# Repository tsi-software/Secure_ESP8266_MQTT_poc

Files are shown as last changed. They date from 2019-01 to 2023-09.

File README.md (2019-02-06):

# Secure ESP8266 MQTT proof of concept
*Copyright (c) 2019 Warren Taylor.*

There are many in depth and well documented ESP8266 MQTT tutorials out there. This in not one of them. This is a brief proof of concept where “security first” is the focus, rather than an afterthought. The goal of this project is to have a documented and working **secure** MQTT Broker and Client, which can be used as a reference for later projects.
If you’re a first timer this project probably isn’t for you.

## Disclaimer
The following documentation in no way guarantees a secure system.
*See [LICENSE](LICENSE).*

## Features
- MQTT Publish/Subscribe Messaging secured using TLS 1.2
- OTA (Over-the-air) Client firmware updates.
- As of this writing esp8266 Secure Encrypted OTA is still in beta.

# Top Level Components
- Secure MQTT Server setup
- Secure ESP8266 MQTT Client
- AVR SPI Slave

# High Level Design 

## Secure MQTT Broker
The MQTT Broker named Mosquitto is installed on the OpenWRT Wifi router. Running the MQTT Broker on the Wifi router is an experiment, which has so far worked just fine. However, the MQTT Broker could be run on any other computer on the same local area network (LAN). You could even run it on a Raspberry PI if performance isn’t a strict requirement.
<br>[MQTT Broker secure setup - detail](top-level-components/mqtt_server_setup#mqtt-broker-secure-setup)

## Secure ESP8266 MQTT Client
Again, there are many tutorials on how to program the ESP8266 as an MQTT Client. But it's hard to find a single source clearly describing how to program the ESP8266 as a **secure** MQTT Client. As a long time software engineer I know how important security is these days.
<br>[Secure ESP8266 MQTT Client - detail](top-level-components/secure_esp8266_mqtt_client#secure-esp8266-mqtt-client)

## AVR SPI Slave
The original plan was to connect peripherals directly to the ESP8266 data pins but I ran out of pins very quickly. Since I had an unused ATmega168 lying around I though “what the heck” and connected the two chips via SPI with the ESP8266 as the master and the ATmega as the slave. In additions to giving me a lot more data pins this scheme also gave me 5v tolerance. I’m also very happy I went this route because it has led to a number of additional useful ideas, which I will come to later.
<br>[AVR SPI Slave - detail](top-level-components/avr_spi_slave#avr-spi-slave)

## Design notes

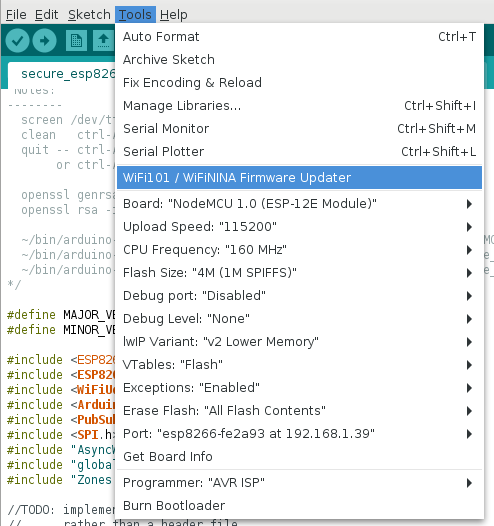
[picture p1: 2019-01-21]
docs/screenshots/arduino_tools_2.png

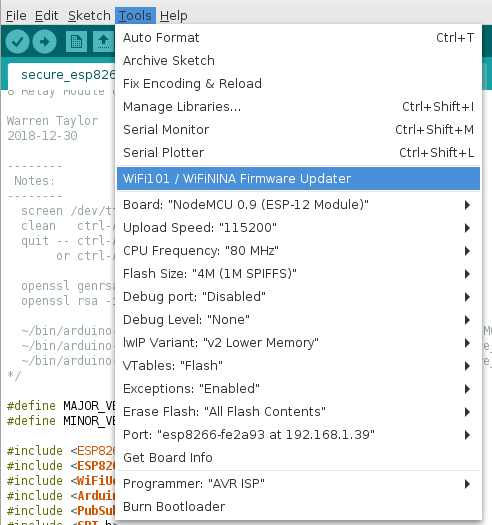
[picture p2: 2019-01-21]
docs/screenshots/arduino_tools_1.png

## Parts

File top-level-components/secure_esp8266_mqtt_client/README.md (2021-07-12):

# Secure ESP8266 MQTT Client
*Copyright (c) 2019-2021 Warren Taylor.*

There are many tutorials on how to program the ESP8266 as an MQTT Client using the Arduino libraries. But it's hard to find a single source clearly describing how to program the ESP8266 as a **secure** MQTT Client. As a long time software engineer I know how important security is these days.

> This project uses the [ESP8266 Arduino Core](https://arduino-esp8266.readthedocs.io/) library and board specifications.

## Disclaimer
The following documentation in no way guarantees a secure system.
*See [LICENSE](../../LICENSE).*

## Security First
At a high level of abstraction secure connections for ESP8266 devices are straight forward when using the arduino-esp8266 **BearSSL::WiFiClientSecure** class.
This is because the **BearSSL::WiFiClientSecure** class extends from the insecure arduino-esp8266 **WiFiClient** class.
What gets complicated is properly initializing a BearSSL::WiFiClientSecure object, which is what this project focuses on.
Once the secure initialization is done the remaining code is implemented mostly the same as the insecure **WiFiClient** class, of which there are many examples.

## ArduinoOTA
The ArduinoOTA library was initially used but later removed from this code because there did not appear to be sufficient resources in the ESP8266 to have a secure connection open by both the MQTT Broker and ArduinoOTA at the same time.
In the future, Secure OTA will be implemented differently in order to coexist with Secure MQTT.

## Source Files

### secure_esp8266_mqtt_client.ino
This is the top level application source code that:
* Connects to the WAP (Wireless Access Point - a.k.a. Wifi Router).
* Securely connects to the MQTT Broker.
* Subscribes to the desired MQTT topics.
* Handles incoming MQTT messages.
* Controls ESP8266 Chip Level Data Pins.
* Configures and manages communications over SPI (Serial Peripheral Interface) to a connected ATmega168. An ATmega168 is used because it has 5V tolerant pins.

### SetupWifi.cpp and SetupWifi.h
This **SetupWifi** class handles the security and encapsulates the arduino-esp8266 **BearSSL::WiFiClientSecure** object.
This class holds the ssid and password of the Wifi Router and implements the code to connect to that router.
This class also holds the ca_cert, client_cert, and client_key used to make secure connections using the **BearSSL::WiFiClientSecure** class.
These certificates and keys were generated when
[Creating the MQTT Keys and Certificates](../mqtt_server_setup#creating-the-mqtt-keys-and-certificates).
Another detail handled by this class, that is not at first obvious, is accurately setting the ESP8266 clock.
This is needed because security certificates can, and should, have an expiry date,
which is very important in order to prevent old and possibly compromised certificates from being reused.
Additionally, UTC (a.k.a. Zulu time) is the internal standard used throughout this project both for consistency
and to avoid potential errors arising from differing time zones and daylight savings time.

### secure_credentials.h
This file contains a copy of the required certificates and keys that were generated when
[Creating the MQTT Keys and Certificates](../mqtt_server_setup#creating-the-mqtt-keys-and-certificates).
> Storing credentials in source code in considered both insecure and bad practice! One of the main reasons for this is because source code that is committed to your revision control system becomes openly accessible (the opposite of secure).
In a subsequent version of this project "secure_credentials.h" will be removed and
replaced with a method of securely injecting credentials into the target devices.

### AsyncWait.h
AsyncWait.h is code that is independent of security but still worth mentioning here.
One of my prime directives is to never write blocking code (code that waits for something to happen but also prevents any other code from executing).
AsyncWait allows me to write code in one place that waits for a duration of time but still allows the main loop() to continue processing.
I think I may write an entirely separate blog on this topic.

### Zones.h
This is application level code, which is independent of security and, therefore, not discussed here.

### globals.h
This is application level code, which is independent of security and, therefore, not discussed here.

### Hardware Schematics
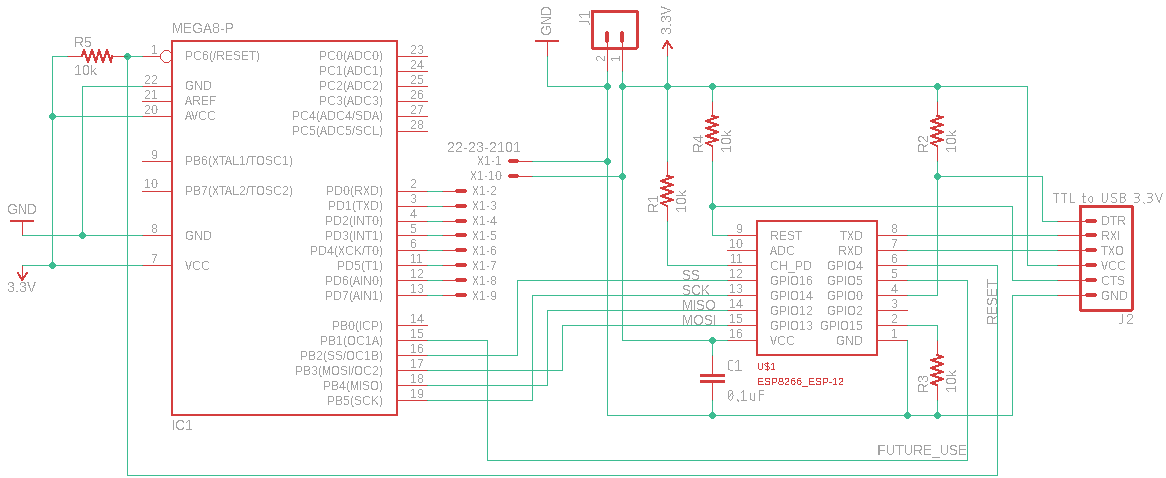
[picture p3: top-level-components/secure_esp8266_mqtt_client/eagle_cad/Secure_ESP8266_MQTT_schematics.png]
Schematics


## Arduino Configuration
### Arduino Board Manager
The points here were taken from [arduino-esp8266 readthedocs](https://arduino-esp8266.readthedocs.io/en/latest/installing.html)

* Run **Arduino** and open **Preference**
* Enter *https://arduino.esp8266.com/stable/package_esp8266com_index.json* into Additional Board Manager URLs field.
* Open **Boards Manager**, search for *esp8266*, and install the appropriate board and version. 

### Arduino Library Manager
Open the Arduino Library Manager and install the following libraries:

* PubSubClient by Nick O'Leary

## MQTT Client References
* <https://arduino-esp8266.readthedocs.io/en/latest/esp8266wifi/readme.html>
* <https://arduino-esp8266.readthedocs.io/en/latest/esp8266wifi/bearssl-client-secure-class.html>
* <https://github.com/esp8266/Arduino/blob/master/doc/esp8266wifi/bearssl-client-secure-class.rst>
* <https://github.com/esp8266/Arduino/tree/master/libraries/ESP8266WiFi/examples>
* <https://github.com/esp8266/Arduino/blob/master/libraries/ESP8266WiFi/src/WiFiClientSecureBearSSL.h>
* <https://pubsubclient.knolleary.net/>

## Future Features
### OTA (Over-the-Air) Updates
Future versions of this ESP8266 MQTT Client will have secure OTA updates enabled.
The **ESP8266** will be updated in a manner similar to that of the ArduinoOTA code but instead using the existing secure MQTT connection in order to keep memory use minimal.
The **AVR SPI Slave** will be updated over-the-air by using the ESP8266 as an AVR ISP (In-System Programming) device. Again using the existing secure MQTT connection in order to keep memory use minimal.

# cp210x USB Driver
https://askubuntu.com/questions/941594/installing-cp210x-driver
https://www.silabs.com/products/development-tools/software/usb-to-uart-bridge-vcp-drivers

------
 e.g.
------
$ uname -r
4.9.0-13-amd64

$ uname --all
Linux gonzo 4.9.0-13-amd64 #1 SMP Debian 4.9.228-1 (2020-07-05) x86_64 GNU/Linux

$ lsb_release --all
No LSB modules are available.
Distributor ID: Debian
Description:    Debian GNU/Linux 9.13 (stretch)
Release:        9.13
Codename:       stretch

----------------------------------------
 From the directory containing cp210x.c
----------------------------------------
make
sudo chown root:root cp210x.ko
sudo modprobe --remove --verbose cp210x
sudo cp /lib/modules/"$(uname -r)"/kernel/drivers/usb/serial/cp210x.ko  /lib/modules/"$(uname -r)"/kernel/drivers/usb/serial/cp210x.ko.ORIG1
ls -l /lib/modules/"$(uname -r)"/kernel/drivers/usb/serial
sudo cp cp210x.ko /lib/modules/"$(uname -r)"/kernel/drivers/usb/serial
make clean

cd /lib/modules/"$(uname -r)"/kernel/drivers/usb/serial
#sudo modprobe --verbose usbserial
sudo modprobe --verbose cp210x

sudo dmesg --human --reltime | tail

sudo modinfo usbserial
sudo modinfo cp210x

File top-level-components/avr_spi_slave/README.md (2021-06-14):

# AVR SPI Slave
*Copyright (c) 2019-2020 Warren Taylor.*

## Disclaimer
The following documentation in no way guarantees a secure system.
*See [LICENSE](../../LICENSE).*

## Overview
The original plan was to connect peripherals directly to the ESP8266 data pins but I ran out of pins very quickly. Since I had an unused ATmega168 lying around I though "what the heck" and connected the two chips via SPI with the ESP8266 as the master and the ATmega as the slave. In additions to providing a larger number of data pins this scheme also provided 5v tolerance.

This AVR SPI Slave simply receives a byte value from the controlling ESP8266 and then sets the output of Port D to this by value. In other words the ESP8266 is setting the eight Port D output pins via SPI. That's all.

However, a huge advantage for the future is that with a bit more programming in the ESP8266 the AVR can be programmed Over-the-Air, which means it can be made to do anything.

This in not an Arduino Sketch.
This is very simple native AVR firmware.
Why? Because I didn't know how easy native AVR programming was until I tried it.

## Requirements
* ATmega168 (or similar)
* avr-gcc
* AVR ISP (In-System Programming) device

## Wiring up the AVR
I’m going to defer to two other web sites that do an excellent job of describing how to wire-up and program the AVR.
* <http://ediy.com.my/index.php/projects/item/86-minimal-arduino-with-8mhz-internal-clock> 
* <http://www.ladyada.net/learn/avr/index.html> 

## Programming the AVR
Connect you development computer to the ATmega168 as described above.
Then, from this "avr_spi_slave" directory, run:
```bash
make test_conn
make program_fuses
make program
```
Note: "make program_fuses" only needs to be run once, not each time the source file changes.

## AVR References
* <http://ediy.com.my/index.php/projects/item/86-minimal-arduino-with-8mhz-internal-clock>
* <http://www.ladyada.net/learn/avr/index.html>
* <https://en.wikipedia.org/wiki/AVR_microcontrollers>
* <https://www.arduino.cc/en/Tutorial/ArduinoISP>
* <https://www.arduino.cc/en/Main.ArduinoISP>
* <http://maxembedded.com/2015/06/setting-up-avr-gcc-toolchain-on-linux-and-mac-os-x/>
* <https://www.microchip.com/mplab/avr-support/avr-and-arm-toolchains-c-compilers>
* <https://gcc.gnu.org/wiki/avr-gcc>
* <https://www.nongnu.org/avr-libc/>
* <http://www.engbedded.com/fusecalc/>

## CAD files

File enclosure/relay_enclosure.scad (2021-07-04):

// relay_enclosure.scad
// Copyright (c) 2021 Warren Taylor

use </home/wtaylor/data/openscad/MCAD/boxes.scad>

cli_fn = 32; // This value can be changed by the command line.
$fn = cli_fn;
fn_Low  = 32;
fn_Med  = fn_Low * 2;
fn_High = fn_Low * 4;

//$fn = $preview ? 12 : 72;

inchesToMm = 25.4;
wallWidth = 2.0;
supportWidth = 3.25;
spacing = 1 + (4.2 - 1.55);
gap = 0.5;
small_gap = 0.12;
omega = 0.001;

base_corner_radius = 1;


relay_board_width = 1.72;
controller_board_width = 4.0;
full_relay_board_width = 1.55;
full_controller_board_width = 4.0;

relay_board =     [138.1+gap*2, 50.26+gap*2, 1.72+gap*1];
controller_board = [88.0+gap*2, 56.40+gap*2, 1.55+gap*1];
board_separation = 47.0;

lower_enclosure_inside = [
    max(relay_board.x, controller_board.x) + gap*0,
    board_separation + relay_board.z + controller_board.z + spacing*3,
    max(relay_board.y, controller_board.y),
];
lower_enclosure_outside = [
    lower_enclosure_inside.x + wallWidth*2,
    lower_enclosure_inside.y + wallWidth*2,
    lower_enclosure_inside.z + wallWidth*1,
];

support_rail = [
    supportWidth,
    spacing * 2 + supportWidth,
    min(relay_board.y, controller_board.y),
];


lock_screw_hole_diameter = 5.5;
lock_screw_hole_radius = lock_screw_hole_diameter/2;
lock_screw_hole_offset = 10;

upper_enclosure_inside = [
    lower_enclosure_outside.x + gap*2,
    lower_enclosure_outside.y + gap*2,
    lower_enclosure_outside.z + gap*2 + lock_screw_hole_offset + lock_screw_hole_diameter + supportWidth
];
upper_enclosure_outside = [
    upper_enclosure_inside.x + wallWidth*2,
    upper_enclosure_inside.y + wallWidth*2,
    upper_enclosure_inside.z + wallWidth*1,
];
hangerWidth = supportWidth;


translate([0, -lower_enclosure_outside.y*0.6, 0]) {
    lower_enclosure();
}

translate([0, upper_enclosure_outside.y*0.6, 0]) {
    upper_enclosure();
}



module circuit_boards() {
    translate([0, (relay_board.z + board_separation)/2, relay_board.y/2])
    rotate([90,0,0])
    {
        cube(relay_board, center = true);
    }

    translate([0, -(controller_board.z + board_separation)/2, controller_board.y/2])
    rotate([90,0,0])
    {
        cube(controller_board, center = true);
    }
}


module lower_enclosure() {
    difference() {
        union() {
            // Outside & Inside walls of lower enclosure.
            translate([0, 0, lower_enclosure_inside.z/2]) {
                difference() {
                    translate([0, 0, -(wallWidth/2 + omega)]) {
                        roundedCube(
                            size = lower_enclosure_outside,
                            r = base_corner_radius,
                            sidesonly = false,
                            center = true,
                            $fn = fn_High
                        );
                    }
                    translate([0, 0, base_corner_radius]) {
                        roundedCube(
                            size = [
                                lower_enclosure_inside.x,
                                lower_enclosure_inside.y,
                                lower_enclosure_inside.z + base_corner_radius*2
                            ],
                            r = base_corner_radius,
                            sidesonly = false,
                            center = true,
                            $fn = fn_Low
                        );
                    }//translate
                }//difference
            }//translate

            // Support Rails for relay board.
            for (offset = [-1, +1]) {
                translate([
                    offset * (lower_enclosure_inside.x/2 - support_rail.x/2 + omega),
                    lower_enclosure_inside.y/2 - support_rail.y/2 + omega,
                    support_rail.z/2 - omega
                ])
                {
                    cube(support_rail, center=true);
                }//translate
            }//for

            // Support Rails for controller board.
            for (offset = [-1, +1]) {
                translate([
                    offset * (controller_board.x*0.5 - support_rail.x*0 + omega),
                    -(lower_enclosure_inside.y/2 - support_rail.y/2 + omega),
                    support_rail.z/2 - omega
                ])
                {
                    cube([support_rail.x*2, support_rail.y, support_rail.z], center=true);
                }//translate
            }//for
        }//union

        //++ difference ++
        #circuit_boards();
    }
}


module upper_enclosure() {
    // Outside & Inside walls of upper enclosure.
    translate([0, 0, upper_enclosure_inside.z/2])
    //rotate([0,180,0]) //JUST TESTING!!!
    {
        difference() {
            translate([0, 0, -(wallWidth/2 + omega)]) {
                union() {
                    // outside
                    roundedCube(
                        size = upper_enclosure_outside,
                        r = base_corner_radius + gap,
                        sidesonly = false,
                        center = true,
                        $fn = fn_High
                    );
                    translate([0, -upper_enclosure_outside.y*0.5, -upper_enclosure_inside.z/2]) {
                        hanger();
                    }
                }
            }
            //++ difference ++
            translate([0, 0, base_corner_radius]) {
                // inside
                roundedCube(
                    size = [
                        upper_enclosure_inside.x,
                        upper_enclosure_inside.y,
                        upper_enclosure_inside.z + base_corner_radius*2
                    ],
                    r = base_corner_radius + gap,
                    sidesonly = false,
                    center = true,
                    $fn = fn_Low
                );

                // Lock Screw holes.
                translate([0, 0, upper_enclosure_inside.z/2 - lock_screw_hole_diameter - supportWidth])
                rotate([0,90,0])
                {
                    cylinder(
                        r = lock_screw_hole_radius,
                        h = upper_enclosure_outside.x*1.5,
                        center = true,
                        $fn = fn_High
                    );
                    //lock_screw_hole_radius
                    //lock_screw_hole_offset
                }

            }//translate
        }//difference
    }//translate
}


module hanger() {
    screw_cap_diameter = 6;
    screw_cap_radius = screw_cap_diameter/2;
    screw_thread_diameter = 4;
    screw_thread_radius = screw_thread_diameter/2;

    hanger_offset_r1 = screw_cap_radius + supportWidth; // + hangerWidth; //+hangerWidth to create a bevel.
    hanger_offset_r2 = screw_cap_radius + supportWidth;

    hanger_centers = [
        [
            upper_enclosure_outside.x*0.5,
            0,
            upper_enclosure_outside.z*0.66
        ],
        [
            upper_enclosure_outside.x + hanger_offset_r1 + wallWidth,
            0,
            hanger_offset_r1+base_corner_radius
        ],
        [
            0 - (hanger_offset_r1 + wallWidth),
            0,
            hanger_offset_r1+base_corner_radius
        ],
    ];

    translate([-hanger_centers[0].x, hangerWidth/2, 0])
    difference()
    {
        hull() {
            for (ndx = [0 : len(hanger_centers)-1]) {
                translate(hanger_centers[ndx]) {
                    if (ndx == -1) {
                        //
                    } else {
                        rotate([-90, 0, 0]) {
                            //TODO: use a donut here instead of a cylinder.
                            cylinder(
                                r1 = hanger_offset_r1,
                                r2 = hanger_offset_r2,
                                h = hangerWidth,
                                center = true,
                                $fn = fn_Low
                            );
                        }
                    }//if-else
                }//translate
            }//for
        }//hull
        //++ difference ++
        for (ndx = [0 : len(hanger_centers)-1]) {
            translate(hanger_centers[ndx]) {
                if (ndx == 0) {
                    //
                } else {
                    rotate([-90, 0, 0]) {
                        cylinder(
                            r = screw_thread_radius,
                            h = hangerWidth+1,
                            center = true,
                            $fn = fn_Low
                        );
                    }
                }//if-else
            }//translate
        }//for
    }//difference & translate
}

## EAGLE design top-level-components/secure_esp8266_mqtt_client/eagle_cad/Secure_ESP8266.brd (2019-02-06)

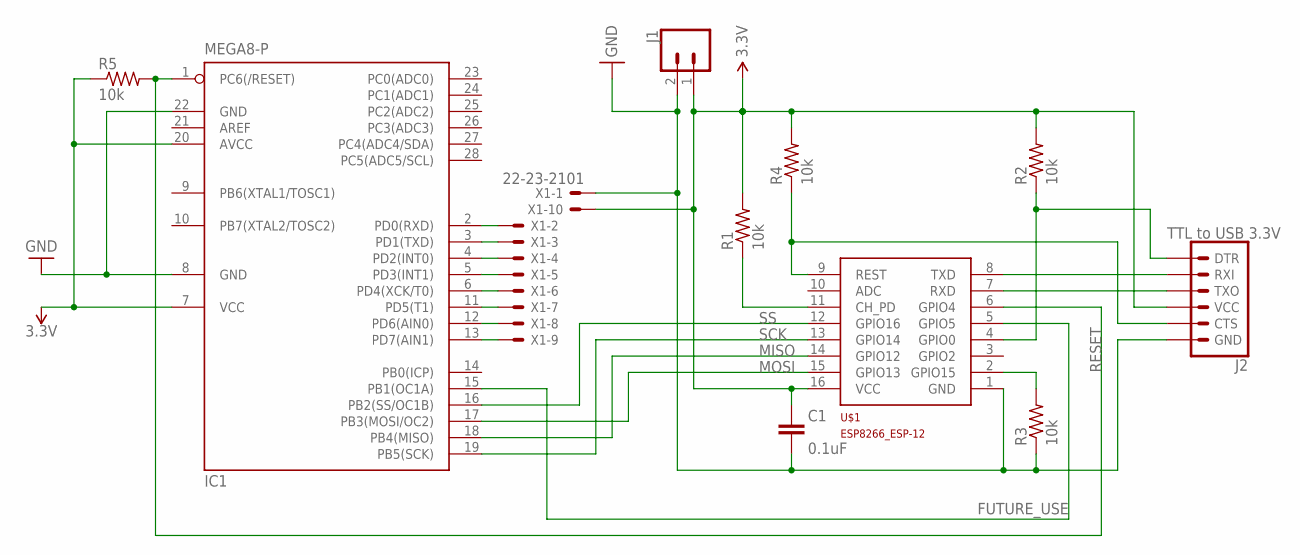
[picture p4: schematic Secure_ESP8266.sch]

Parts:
C1: 0.1uF; CAP-PTH-SMALL-KIT
IC1: MEGA8-P; DIL28-3
J1: CONN_02PTH3; 1X02_LONGPADS
J2: TTL to USB 3.3V; 1X06_LONGPADS
R1, R2, R3, R4, R5: 10k; 0204/7
U$1: ESP8266_ESP-12; ESP8266-ESP12
X1: 22-23-2101

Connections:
3.3V: C1.2, IC1.7 (VCC), IC1.20 (AVCC), J1.1, J2.4 (VCC), R1.2, R2.2, R4.2, R5.1, U$1.16 (VCC), X1.10
D0: IC1.2 (PD0(RXD)), X1.2
D1: IC1.3 (PD1(TXD)), X1.3
D2: IC1.4 (PD2(INT0)), X1.4
D3: IC1.5 (PD3(INT1)), X1.5
D4: IC1.6 (PD4(XCK/T0)), X1.6
D5: IC1.11 (PD5(T1)), X1.7
D6: IC1.12 (PD6(AIN0)), X1.8
D7: IC1.13 (PD7(AIN1)), X1.9
FUTURE_USE: IC1.15 (PB1(OC1A)), U$1.5 (GPIO5)
GND: C1.1, IC1.8 (GND), IC1.22 (GND), J1.2, J2.6 (GND), R3.1, U$1.1 (GND), X1.1
MISO: IC1.18 (PB4(MISO)), U$1.14 (GPIO12)
MOSI: IC1.17 (PB3(MOSI/OC2)), U$1.15 (GPIO13)
unnamed: J2.5 (CTS), R4.1, U$1.9 (REST)
unnamed: R1.1, U$1.11 (CH_PD)
unnamed: R3.2, U$1.2 (GPIO15)
unnamed: J2.1 (DTR), R2.1, U$1.4 (GPIO0)
unnamed: J2.2 (RXI), U$1.8 (TXD)
unnamed: J2.3 (TXO), U$1.7 (RXD)
RESET: IC1.1 (PC6(/RESET)), R5.2, U$1.6 (GPIO4)
SCK: IC1.19 (PB5(SCK)), U$1.13 (GPIO14)
SS: IC1.16 (PB2(SS/OC1B)), U$1.12 (GPIO16)

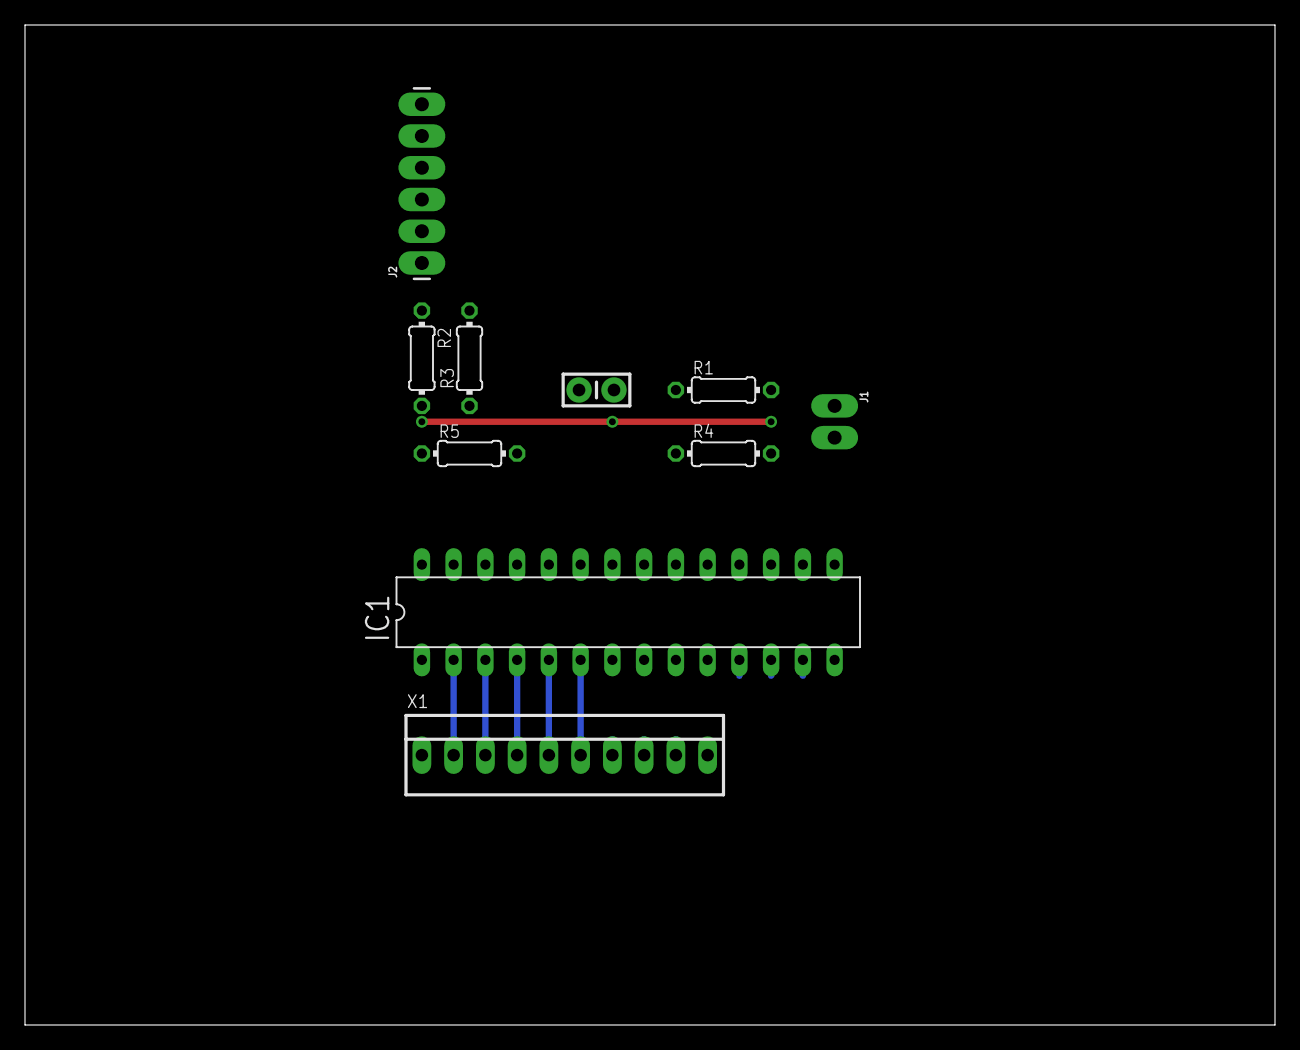
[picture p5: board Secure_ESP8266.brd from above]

Board: 2 copper layers, 100.0 x 80.0 mm, 11 parts (1 on the bottom side), 22 nets.

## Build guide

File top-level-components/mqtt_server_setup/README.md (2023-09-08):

# MQTT Broker secure setup
*Copyright (c) 2019-2023 Warren Taylor.*

Here are the basics of how to install, configure, and secure the “Mosquitto” MQTT Broker on an already properly configured and running installation of [OpenWRT](https://openwrt.org/). However, the MQTT Broker can run on any computer on a local area network (LAN). You could even run it on a Raspberry PI if performance isn’t a strict requirement. So the following instruction should be adaptable to most modern operating systems.

## Disclaimer
The following documentation in no way guarantees a secure system.
*See [LICENSE](../../LICENSE).*

## Install Mosquitto Broker and Client
With ssh (or similar) log into your OpenWRT router.
```bash
ssh root@your-router-hostname
opkg install mosquitto-ssl mosquitto-client-ssl libmosquitto-ssl
```

## Create "mosquitto" user if it does not already exist
```bash
useradd -M mosquitto
usermod -L mosquitto
```

## Create a directory to securely hold your certificates
*(Keys and Certificates can be generate on any computer as long as the required files are securely copied to the server and all keys are securely stored.)*
```bash
mkdir /root/mosquitto
chmod go-rwx /root/mosquitto
chown mosquitto:mosquitto /root/mosquitto
cd /root/mosquitto
```

## Creating the MQTT Keys and Certificates
The documentation below talks a lot about Keys, Certificates, Certificate Authorities, etc...
Rather than trying to rewrite the very good documentation others have already put a great deal of effort into, I refer you to some of their work:
* [SSL and SSL Certificates Explained For Beginners](http://www.steves-internet-guide.com/ssl-certificates-explained/)
* [Introduction to MQTT Security Mechanisms](http://www.steves-internet-guide.com/mqtt-security-mechanisms/)
* [Mosquitto SSL Configuration -MQTT TLS Security](http://www.steves-internet-guide.com/mosquitto-tls/)
* [Securing a Mosquitto Server](https://dzone.com/articles/mqtt-security-securing-a-mosquitto-server)

**NEVER** use the same key and certificate to secure more than one device.
If one device becomes compromised then all devices secured with the same key and certificate are also compromised.<br>
When generating your credentials it is important to use different subject parameters for your CA, server and client certificates.<br>
**Every time you are prompted for the CN (Common Name), enter your same server hostname.**
If you don't know your exact hostname then run something like:
```bash
uci show system
```

### Create an X509 CA key and certificate for self-signing
*(Determine and securely store a PEM Pass Phrase, which is used to protect your CA Key)*
```bash
openssl req -new -x509 -days 365 -extensions v3_ca -keyout mosq_ca.key -out mosq_ca.crt -subj "/C=CA/ST=BC/L=your-city/O=ca.your-domain.com/OU=ca/CN=your-hostname/emailAddress=your@email.com"
```
Subject Parameters:
* C - Country
* ST - State
* L - City
* O - Organization
* OU - Organization Unit
* CN - Common Name (eg: the main domain the certificate should cover)
* emailAddress - main administrative point of contact for the certificate

To verify:
```bash
openssl x509 -in mosq_ca.crt -noout -text
```

### Generate the MQTT Server private key
```bash
openssl genrsa -out mosq_serv.key 2048
```
### Generate the MQTT Server self-signed certificate
```bash
openssl req -new -key mosq_serv.key -out mosq_serv.csr -subj "/C=your-country/ST=your-state/L=your-city/O=server.your-domain.com/OU=server/CN=your-hostname/emailAddress=your@email.com"
```
### Generate the CA signed certificate to use in the MQTT Mosquitto Server
```bash
openssl x509 -req -in mosq_serv.csr -CA mosq_ca.crt -CAkey mosq_ca.key -CAcreateserial -out mosq_serv.crt -days 365
```

### Generate the MQTT Client private key
```bash
openssl genrsa -out mosq_client.key 2048
```

### Generate the MQTT Client self-signed certificate
```bash
openssl req -new -key mosq_client.key -out mosq_client.csr -subj "/C=your-country/ST=your-state/L=your-city/O=client.your-domain.com/OU=client/CN=your-hostname/emailAddress=your@email.com"
```

### Generate the CA signed certificate to use in the MQTT Client
```bash
openssl x509 -req -in mosq_client.csr -CA mosq_ca.crt -CAkey mosq_ca.key -CAcreateserial -out mosq_client.crt -days 365
```

### Increase the security of the files just created
```bash
chmod go-rwx /root/mosquitto/*
chown mosquitto:mosquitto /root/mosquitto/*
```

## Mosquitto server config
**/etc/mosquitto/mosquitto.conf**
```
port 8883
cafile /etc/mosquitto/mosq_ca.crt
keyfile /etc/mosquitto/mosq_serv.key
certfile /etc/mosquitto/mosq_serv.crt
protocol mqtt
tls_version tlsv1.2
require_certificate true
```

### Copy the necessary certificates and key
```bash
cp /root/mosquitto/mosq_ca.crt   /etc/mosquitto/mosq_ca.crt
cp /root/mosquitto/mosq_serv.key /etc/mosquitto/mosq_serv.key
cp /root/mosquitto/mosq_serv.crt /etc/mosquitto/mosq_serv.crt
```

## Restart the Mosquitto Broker
```bash
service mosquitto stop
service mosquitto start
```

## Run a quick test
The following command should turn on zone 2 for 2 minutes (i.e. 120 seconds).
Try running it now, even if the MQTT client has not yet been setup, in order to check for any errors that may occur on the server side.
```bash
mosquitto_pub -h your-hostname -p 8883 \
    --cafile mosq_ca.crt --cert mosq_serv.crt --key mosq_serv.key \
    --debug --topic irrigation/zone/on -m "2 120"
```

### Error: The connection was refused.
If you are using a newer version of the Mosquitto Broker
you may get the following error messages:
```
Client (null) sending CONNECT
Client (null) received CONNACK (5)
Connection error: Connection Refused: not authorised.
Error: The connection was refused.
```
The quick solution is to update **mosquitto.conf** with the following line
and then Restart the Mosquitto Broker:
```
allow_anonymous true
```
However, this solution is a "double edge sword".
Sure, it gets things running but you may now be less secure than you require.
A more complicated configuration could include:
```
...
allow_anonymous false
use_identity_as_username true
...
```
Or even require user name and password in addition to using security certificates and keys.

There are many more Mosquitto Security related configuration settings but
I cannot tell you what to do because everyones security requirements are different
and these are getting into complicated configurations that are beyond the scope of this project.

## MQTT Server References
* <https://manpages.debian.org/stretch/mosquitto/mosquitto-tls.7.en.html>
* <https://manpages.debian.org/stretch/mosquitto/mosquitto_passwd.1.en.html>
* <https://www.openssl.org/docs/man1.1.0/apps/>
* <https://github.com/eclipse/mosquitto>

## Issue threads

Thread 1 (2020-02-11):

What if the certificate expires?

cwhzzang, 2020-02-11:
Hello, thank you for your contributions.
I executed your program.
It worked very well.
But I have a problem.
I entered my server credentials in the file "secure_credentials.h".
But my server certificate will expire someday.
When certificate expire, I will extend and replace the server's certificate in server.
After that, do I need to re-modify this file "secure_credentials.h"?
Or is ESP_8266 able to connect to the server without modification?

lopic34, 2020-02-12:
Hello,
I have the same use case and the same question :
what 's about reloading a certificate after expiration (need to reflash ESP) ?

And thank you for the great job !

tsi-software, 2020-03-04:
Yes. When the certificate expires you have to:
- generate a new certificate,
- update secure_credentials.h,
- recompile the source code,
- flash the ESP.

Please keep in mind that I created this project as a proof of concept. My intention was to show, and prove, the steps required to make a secure connection. As I move forward with another more production ready project, I will make efforts to add a “secure over-the-air certificate update” feature, and other usability features, to this project.

lopic34, 2020-03-14:
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

> Please keep in mind that I created  this project as a proof of concept. My intention was to show, and prove, the steps required to make a secure connection. As I move forward with another more production ready project, I will make efforts to add a “secure over-the-air certificate update” feature, and other usability features, to this project.

Thank for the process to re-inject the new certificate manually, and I agree, it is OK for a POC.

About the "auto-renew", do you plan about a regulary checking for a certificate on a http authenticated server or "OTA update" process ?

tsi-software, 2020-06-14:
My plan is to have a database that keeps track of the expiry dates of all relevant certificates. Then, where appropriate, kick off an automated process to update the certificates that are close to expiring. I feel that “regularly checking” certificates is not as secure because there is a possibility of being spoofed.

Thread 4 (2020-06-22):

SPI Security

woodz-, 2020-06-22:
One question: have you thought of securing your SPI comm either?
Couldn't it be a security hole if you provide firmware updates OTA-ly? Hardware could be easily hacked into to manipulate SPI comm.
Wouldn't it be interesting to have secure SPI?
Again, it is just a question and likely far away from reality. But I'd be interested what a sw-dev with profession thinks about.

When I started with Aduino, my naive understanding was: "everything would be run on AVRs". When I'd like to have WiFi, I'd need to order a WiFi module and serially talk to it. This way it would never be possible to secure my comm, since HW-wires are always accessible and there is no out of the box serial securing mechanism on the AVRs.
Very soon I learned, Arduino is far away from this. The IDE supports a lot more than AVR-based HW-boards like the ESPs. Only this way we can have secure comm, by not exposing any HW-wires to the world.

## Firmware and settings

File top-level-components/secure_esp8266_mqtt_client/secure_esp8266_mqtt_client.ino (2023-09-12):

/****
Secure ESP8266 MQTT Client
version 00.02

Author:  Warren Taylor
Created: 2018-12-30
Copyright (c) 2018-2020 Warren Taylor.  All right reserved.

----------
 Features:
----------
MQTT
8 Relay Module controller

Future:
OTA firmware revision

--------
 Notes:
--------
screen /dev/ttyUSB0 115200
clean   ctrl-A C
quit -- ctrl-A k
     or ctrl-A \

------------------------
 CLI compile and upload
------------------------
~/bin/arduino-1.8.8/arduino  ~/github/tsi-software/Secure_ESP8266_MQTT_poc/top-level-components/secure_esp8266_mqtt_client/secure_esp8266_mqtt_client.ino
~/bin/arduino-1.8.8/arduino  --verify  ~/github/tsi-software/Secure_ESP8266_MQTT_poc/top-level-components/secure_esp8266_mqtt_client/secure_esp8266_mqtt_client.ino
~/bin/arduino-1.8.8/arduino  --upload  ~/github/tsi-software/Secure_ESP8266_MQTT_poc/top-level-components/secure_esp8266_mqtt_client/secure_esp8266_mqtt_client.ino

~/bin2/arduino-1.8.15/arduino --verbose --upload secure_esp8266_mqtt_client.ino
*/

#define MAJOR_VER "00"
#define MINOR_VER "03"

#include <Arduino.h>
#include <ESP8266WiFi.h>
#include <PubSubClient.h>
#include <time.h>
#include "AsyncWait.h"
#include "globals.h"
#include "SetupWifi.h"
#include "UpdateRelays.h"
#include "Zones.h"


//TODO: implement secure credentials as a runtime config file
//      rather than a header file.
#include "secure_credentials.h"

SetupWifi setupWifi(
    STASSID, STAPSK,
    CA_CERT_PROG, CLIENT_CERT_PROG, CLIENT_KEY_PROG
);


const char* mqtt_server = MQTT_SERVER;
//IPAddress broker(192,168,1,1); // IP address of your MQTT broker


const char *ID = "sec_mqtt_client_" MAJOR_VER "_" MINOR_VER;  // Name of our device, must be unique
const String TOPIC_ZONE_ON("irrigation/zone/on");
const String TOPIC_ZONE_OFF("irrigation/zone/off");
const String TOPIC_ZONE_STATUS("irrigation/zone/status");


// TODO: Use Metaprogramming to automate the zone indexing.
static ZoneStatus zoneArray[] {
    ZoneStatus(0), ZoneStatus(1), ZoneStatus(2), ZoneStatus(3),
    ZoneStatus(4), ZoneStatus(5), ZoneStatus(6), ZoneStatus(7)
};

static Zones zones( zoneArray, sizeof(zoneArray)/sizeof(zoneArray[0]) );
static PubSubClient pubsubClient(setupWifi.getWiFiClient());


// Handle incomming messages from the broker
void callback(char* topic, byte* payload, unsigned int length) {
    String topicStr;
    String payloadStr;

    for (int i = 0; topic[i]; i++) {
        topicStr += topic[i];
    }

    for (unsigned int i = 0; i < length; i++) {
        payloadStr += (char)payload[i];
    }

    DEBUG_LOGLN("");
    DEBUG_LOG("Message arrived - [");
    DEBUG_LOG(topicStr);
    DEBUG_LOG("] ");
    DEBUG_LOGLN(payloadStr);

    if (topicStr == TOPIC_ZONE_ON) {
        callbackZoneOn(topicStr, payloadStr);
    } else if (topicStr == TOPIC_ZONE_OFF) {
        callbackZoneOff(topicStr, payloadStr);
    } else if (topicStr == TOPIC_ZONE_STATUS) {
        callbackZoneStatus(topicStr, payloadStr);
    }
}


void callbackZoneOn(const String &topicStr, const String &payloadStr) {
    MilliSec currentMilliSec = millis();

    // Payload in "[Zone-Index] [Duration-in-seconds]"
    String buffer(payloadStr);
    String zoneIndexStr;
    String durationStr;
    buffer.trim();
    int delimIndex = buffer.indexOf(' ');
    if (delimIndex < 0) {
        // Delimeter not found! Leave 'durationStr' empty.
        zoneIndexStr = buffer;
    } else {
        zoneIndexStr = buffer.substring(0, delimIndex);
        durationStr = buffer.substring(delimIndex + 1);
    }

    if (zoneIndexStr.length() <= 0 || durationStr.length() <= 0) {
        // Invalid Payload:
        DEBUG_LOGLN("Invalid Payload! zoneIndexStr=" + zoneIndexStr + ", durationStr=" + durationStr);
        return;
    }

    unsigned zoneIndex = (unsigned)zoneIndexStr.toInt();
    int duration = durationStr.toInt();
    if (duration < 0) {
        duration = 0;
    }

    bool changed = false;
    if (duration > 0) {
        changed = zones.turnOn(zoneIndex, (unsigned)duration, currentMilliSec);
    } else {
        changed = zones.turnOff(zoneIndex);
    }
    if (changed) {
        updateRelays(zones);
    }
}


void callbackZoneOff(const String &topicStr, const String &payloadStr) {
    //MilliSec currentMilliSec = millis();
    //TODO: if needed.
}


void callbackZoneStatus(const String &topicStr, const String &payloadStr) {
    //MilliSec currentMilliSec = millis();
    //TODO: if needed.
}


/****
void process_response(String &response, byte pin, const char *state_topic) {
    if(response == "on") {
        digitalWrite(pin, HIGH);
        pubsubClient.publish(state_topic,"on");
        //DEBUG_LOG(pin);
        //DEBUG_LOG("=HIGH, ");
        //DEBUG_LOG(state_topic);
        //DEBUG_LOGLN("=on");
    } else if(response == "off") { // Turn the light off
        digitalWrite(pin, LOW);
        pubsubClient.publish(state_topic,"off");
        //DEBUG_LOG(pin);
        //DEBUG_LOG("=LOW, ");
        //DEBUG_LOG(state_topic);
        //DEBUG_LOGLN("=off");
    }
}
****/


// Reconnect to the MQTT client.
void reconnectToMQTT(MilliSec currentMilliSec) {
  if (pubsubClient.connected()) {
    // We are connected so nothing further needs to be done.
    return;
  }

  static AsyncWait waitToRetry;
  if (waitToRetry.isWaiting(currentMilliSec)) {
    return;
  }

  DEBUG_LOG("Attempting MQTT connection...");
  // Attempt to connect
  if (pubsubClient.connect(ID)) {
    DEBUG_LOGLN("connected");

    pubsubClient.subscribe(TOPIC_ZONE_ON.c_str());
    DEBUG_LOG("Subcribed to: ");
    DEBUG_LOGLN(TOPIC_ZONE_ON);

    pubsubClient.subscribe(TOPIC_ZONE_OFF.c_str());
    DEBUG_LOG("Subcribed to: ");
    DEBUG_LOGLN(TOPIC_ZONE_OFF);
    
    pubsubClient.subscribe(TOPIC_ZONE_STATUS.c_str());
    DEBUG_LOG("Subcribed to: ");
    DEBUG_LOGLN(TOPIC_ZONE_STATUS);
    
  } else {
    DEBUG_LOGLN(" try again in 5 seconds.");
    waitToRetry.startWaiting(currentMilliSec, 5000);
  }
}


void setup() {
  #ifdef DEBUG
  Serial.begin(115200); // Start serial communication at 115200 baud
  #endif

  setupWifi.setupWifi();
  //pubsubClient.setServer(broker, 1883);
  pubsubClient.setServer(mqtt_server, 8883);
  pubsubClient.setCallback(callback); // Initialize the callback routine
  zones.Setup();
  updateRelaysSetup();
}


#ifdef DEBUG
void startupTest(MilliSec currentMilliSec) {
  static AsyncWait startupTestWait;
  static uint8_t startupTestValue;
  static bool firstTime = true;
  static const unsigned turnOnSeconds = 1; // 1 second.
  static const unsigned nextIterationDuration = 1250; // 1,250 milliseconds.

  bool changed = false;

  if (firstTime) {
    firstTime = false;
    startupTestValue = 0;
    changed = zones.turnOn(startupTestValue, turnOnSeconds, currentMilliSec);
    startupTestWait.startWaiting(currentMilliSec, nextIterationDuration);
  }

  if (startupTestValue >= 0 && startupTestValue <= 7) {
    if (!startupTestWait.isWaiting(currentMilliSec)) {
      ++startupTestValue;
      changed = zones.turnOn(startupTestValue, turnOnSeconds, currentMilliSec);
      startupTestWait.startWaiting(currentMilliSec, nextIterationDuration);
    }
  }

  if (changed) {
    updateRelays(zones);
  }
}
#endif // DEBUG


void loop() {
    setupWifi.loopWifi();
    if (!setupWifi.isReadyForProcessing()) {
        // The WiFi is not ready yet so
        // don't do any further processing.
        return;
    }

    if (!pubsubClient.connected()) {
        // Reconnect if connection is lost.
        MilliSec currentMilliSec = millis();
        reconnectToMQTT(currentMilliSec);
    }
    pubsubClient.loop();

    { // App code.
        MilliSec currentMilliSec = millis();

        #ifdef DEBUG
        startupTest(currentMilliSec);
        #endif

        bool zonesChanged = zones.Loop(currentMilliSec);
        if (zonesChanged) {
            updateRelays(zones);
        }
    }
}

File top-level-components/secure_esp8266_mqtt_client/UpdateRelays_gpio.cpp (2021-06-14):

/*
 * UpdateRelays_gpio.cpp
 *
 * Author:  Warren Taylor
 * Created: 2020-08-19
 * Copyright (c) 2018-2020 Warren Taylor.  All right reserved.
 */

#include "UpdateRelays.h"

//------------------------------------------------------------------------------
#if defined(UPDATE_RELAYS_USE_GPIO)



static const unsigned short NUM_OF_ZONES = 8;

// FAIL !!!
static uint8_t zonePins[ NUM_OF_ZONES ] = {
    5,  // Zone 0
    4,
    14,
    12,
    13,
    10,
    9,
    5   // Zone 7
};


extern void updateRelaysSetup(void)
{
    for (unsigned short ndx = 0; ndx < NUM_OF_ZONES; ++ndx) {
        // Default to INPUT - High Impedence.
        pinMode(zonePins[ndx], INPUT);
    }
}


void updateRelays(const Zones &zones)
{
    for (unsigned short ndx = 0; ndx < NUM_OF_ZONES; ++ndx) {
        const uint8_t pin = zonePins[ndx];

        // A low output value energizes the relay.
        // A high value (or high impedence) turns off the relay.
        // This is inverted logic.
        if (zones.isZoneOn(ndx)) {
            pinMode(pin, OUTPUT);
            digitalWrite(pin, LOW);
        } else {
            // INPUT - High Impedence.
            pinMode(pin, INPUT);
        }
    }
}


#endif // defined(UPDATE_RELAYS_USE_GPIO)
//------------------------------------------------------------------------------

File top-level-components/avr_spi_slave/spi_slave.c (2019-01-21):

// F_CPU tells util/delay.h our clock frequency
#ifndef F_CPU
#define F_CPU 8000000UL // 8MHz
#endif


//#define DD_MISO   B,4
//#define DD_MOSI   B,3
//#define DD_SCK    B,5
//#define DD_SS     B,2


#include <avr/io.h>
//#include <stdlib.h>
//#include <util/delay.h>


void spi_init_slave( void )
{
    // MISO as OUTPUT
    DDRB = (1<<4);
    //pinMode(MISO, OUTPUT); //Arduino

    /*  Enable SPI.
        SPCR0:
        Bit 7 – SPIE0: SPI0 Interrupt Enable
        Bit 6 – SPE0: SPI0 Enable
        Bit 5 – DORD0: Data0 Order
            0 = the MSB of the data word is transmitted first.
            1 = the LSB of the data word is transmitted first.
        Bit 4 – MSTR0: Master/Slave0 Select
            0 = Slave
            1 = Master
        Bit 3 – CPOL0: Clock0 Polarity
            0 = SCK is low when idle
            1 = SCK is high when idle
        Bit 2 – CPHA0: Clock0 Phase
            0 = data is sampled on the leading edge of SCK
            1 = data is sampled on the trailing edge of SCK
        Bits 1:0 – SPR0n: SPI0 Clock Rate Select n [n = 1:0]
    */
    // MSB First,
    // SCK is low when idle,
    // data is sampled on the leading edge of SCK
    SPCR = (1<<SPE);
}


unsigned char spi_tranceiver( unsigned char data )
{
    // Load data to send.
    SPDR = data;

    // Wait until transmission complete.
    while(!( SPSR & (1<<SPIF) ));

    // Return received data.
    return(SPDR);
}


int main( void ) {
    spi_init_slave();

    // Port D: set all pins to HIGH, and to OUTPUT.
    PORTD = 0xFF;
    DDRD =  0xFF;

    while(1) {
        PORTD = spi_tranceiver( 0 );
    }
}

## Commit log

2019-01-22 Fix a bug: "||" is a short-circuit operator - do not reverse the arguments. Fix a bit of code formatting. Update doc.
    [secure_esp8266_mqtt_client.ino]
2019-02-04 Completely remove all references to ArduinoOTA because there does not appear to be sufficient resources in the esp8266 to have a secure connection open to both the MQTT Broker and ArduinoOTA at the s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
    [secure_esp8266_mqtt_client.ino]
2019-02-06 Documentation updates.
    [Secure_ESP8266.brd, Secure_ESP8266.sch]
2021-06-23 relay_enclosure.scad - work in progress.
    [relay_enclosure.scad]

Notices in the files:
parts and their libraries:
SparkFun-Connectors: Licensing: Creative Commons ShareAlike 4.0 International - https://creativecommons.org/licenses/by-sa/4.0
